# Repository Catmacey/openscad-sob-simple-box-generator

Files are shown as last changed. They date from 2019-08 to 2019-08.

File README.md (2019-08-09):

# OpenSCAD simple 3d printable project boxes

This is an OpenSCAD library for the creation of simple multipart project cases that can be 3d printed.  

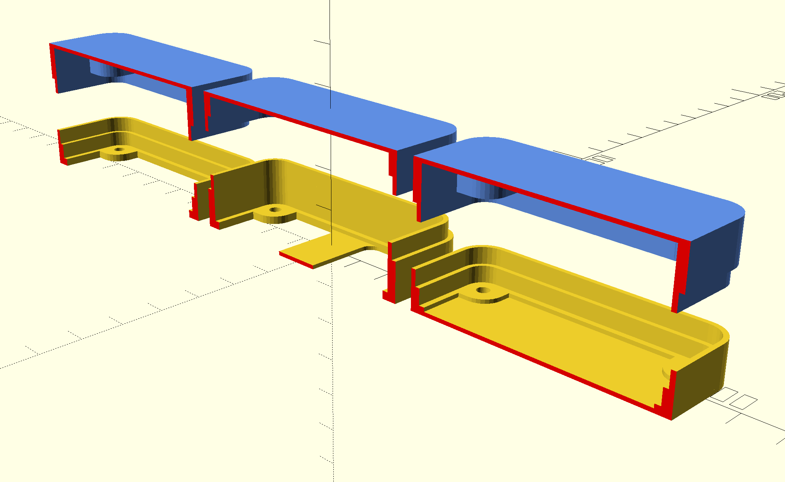
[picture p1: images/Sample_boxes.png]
Sample of three cases showing different options /tests/sob_tests.scad

>This image shows the case variants and is created from /tests/sob_tests.scad

The library is created in [OpenSCAD](http://www.openscad.org/) and is intended for 3d printing using a nothing-special FDM printer with a 0.4mm nozzle.

The box is split into three stacking parts, the top, middle and bottom (Not yet complete) and is designed to house electronics projects that use the Dangerous Prototypes [Sick Of Beige PCB standard](http://dangerousprototypes.com/docs/Sick_of_Beige_standard_PCB_sizes_v1.0).

The height, width and depth of the case are configurable to any dimensions (not just SOB standards) using "global" variables that you can override.  However the rounded corners and mounting hole locations and diameters are fixed based on the SOB standard.

The top and middle parts of the case interlock using an overlapping lip. The middle part of the case can have an open bottom, a single crosmember or be completely solid.  The entire case is held together by screws from underneath that screw into pads in the top.

### Example of DP5031 case

[DP5031 sample SCAD file](tests/DP5031.scad)

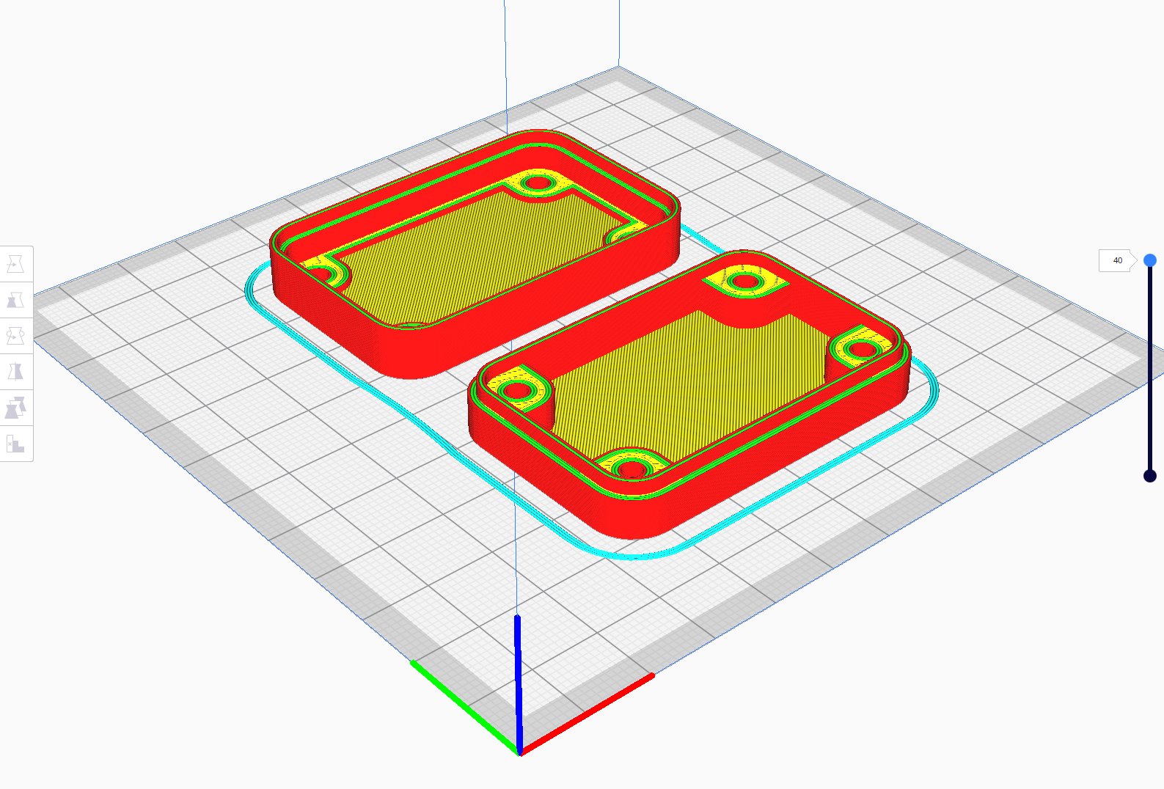
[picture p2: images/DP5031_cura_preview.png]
DP5031 Cura preview

>CURA preview

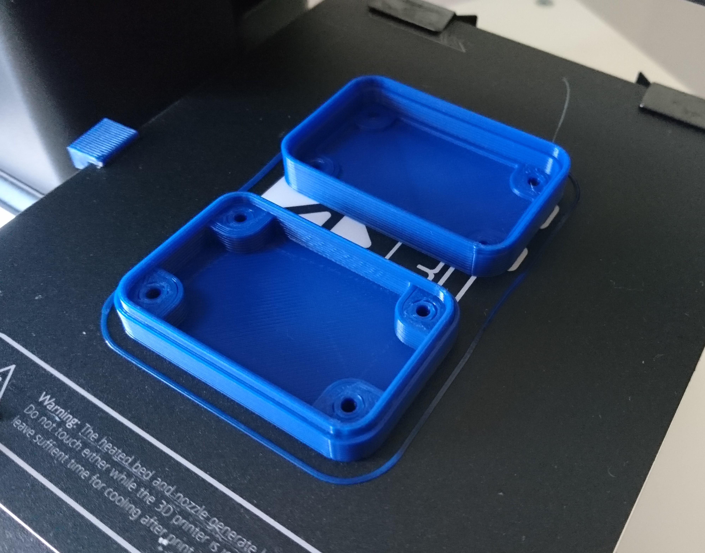
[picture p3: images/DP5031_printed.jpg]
DP5031 On the printer

>Printed in draft 0.4mm nozzle, 0.2mm layers

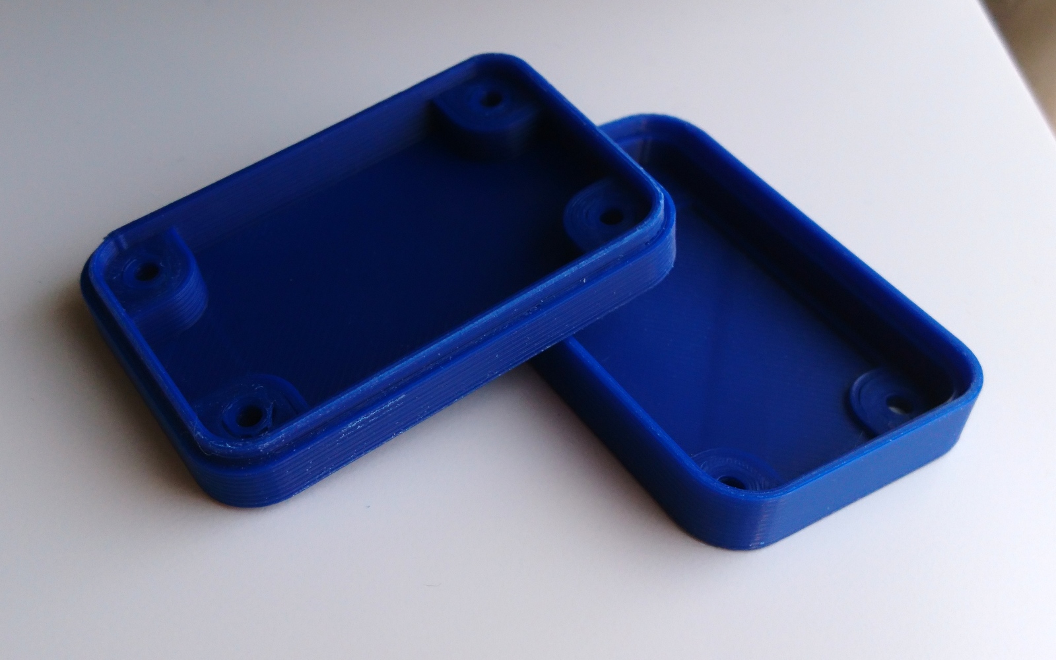
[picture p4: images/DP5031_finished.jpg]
DP5031 After a bit of tidying up

>After a bit of tidying up with a file and cutter to remove the first layer "splodge"

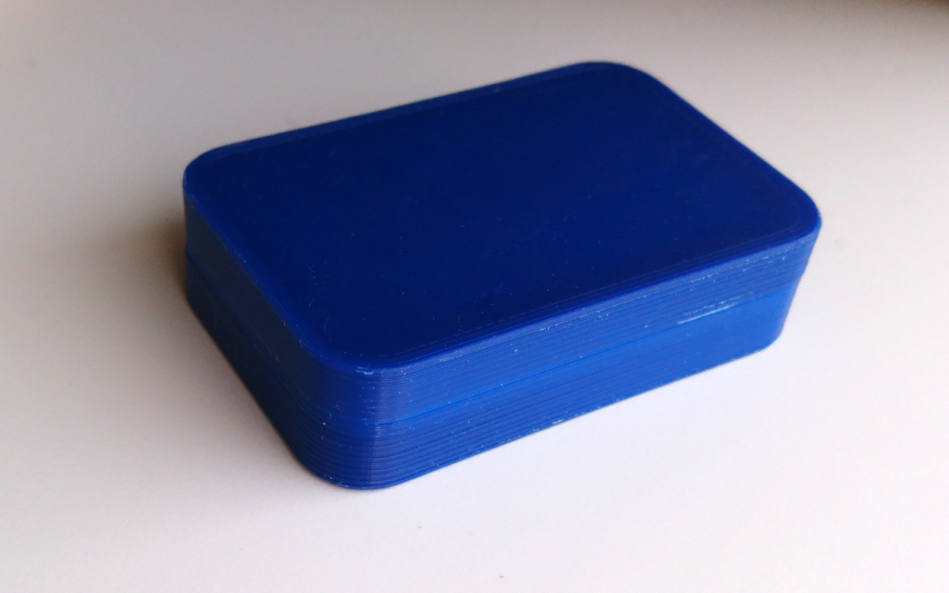
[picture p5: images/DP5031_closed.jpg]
DP5031 Closed case

>Completed case closed.  A small case like this one locks together very tighly.

Copyright (C) 2019 Matt Casey : catmacey.com
This program is free software: you can redistribute it and/or modify it under the terms of the GNU General Public License as published by the Free Software Foundation, either version 3 of the License, or (at your option) any later version.
	
This program is distributed in the hope that it will be useful, but WITHOUT ANY WARRANTY; without even the implied warranty of MERCHANTABILITY or FITNESS FOR A PARTICULAR PURPOSE.  See the GNU General Public License for more details.

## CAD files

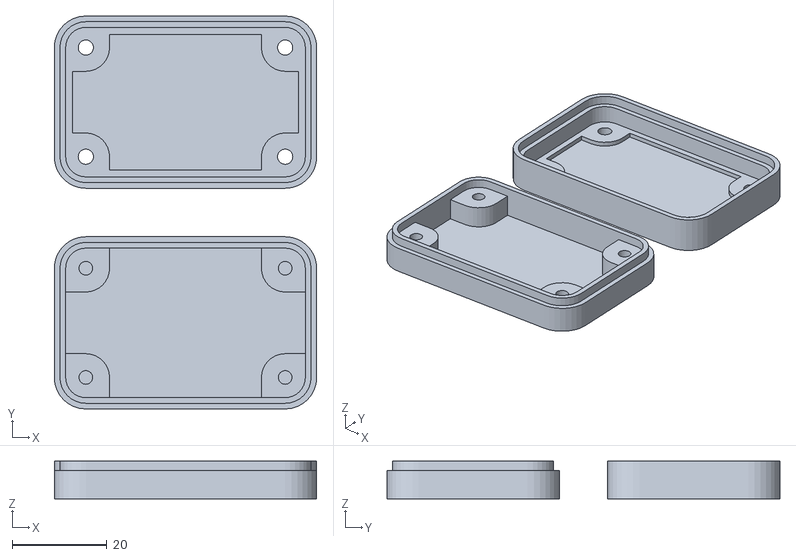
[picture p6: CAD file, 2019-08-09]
tests/DP5031.stl
55.3 x 82.8 x 8.00

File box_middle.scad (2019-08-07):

// Middle part of a SOB box
module sob_box_middle(
		overall_height = 10
	, lip_type = "outer"    // [inner|outer] which half of the lip is this?
	, xmember = 12          // [float] width of the crossmember. 0 for no crossmember
	, hollow = false        // [bool] solid or hollow base
	, cornerpad_thickness   // [float] height of the pads that support the pcb
	, withdrills = true     // [bool] do drill holes pierce through the bottom of the case
){
	union(){
		// Wall and lip
		translate([0,0,SOB_foot_thickness]){
			if(lip_type == "inner"){
				// Overall height does not include the lip
				translate([0,0,overall_height - SOB_foot_thickness]) sob_box_lip(type = lip_type);
				sob_wall(overall_height - SOB_foot_thickness);
			}
			if(lip_type == "outer"){
				translate([0,0,overall_height - SOB_foot_thickness - SOB_lip_thickness]) sob_box_lip(type = lip_type);
				sob_wall(overall_height - SOB_foot_thickness - SOB_lip_thickness);
			}
		}

		// Foot rim that the pcb sits on
		face(thickness = SOB_foot_thickness, hollow=true);

		// Thin xmember
		if(!hollow){
			face(thickness = SOB_foot_thickness/2, xmember = xmember, withdrills = withdrills);
		}

		// Pads that support the pcb
		// Default is that the corner pads in the middle part are flush
		// with the footrim but they can be thicker if you wish
		cp_thickness = 
			(cornerpad_thickness != undef)
			?cornerpad_thickness
			:SOB_foot_thickness
		;
		cornerpads(
			  drill = SOB_drill_radius
			, thickness = cp_thickness
		);
	}
}

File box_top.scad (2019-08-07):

// Top part of SOB box
module sob_box_top(
		overall_height = 10
	, lip_type = "inner"   // [inner|outer] which half of the lip is this?
	, cornerpad_thickness  // [float] height of the pads that support the pcb
){

	// This colour is of course completely optional :o)
	color("CornflowerBlue")
	union(){
		// Top face of the case
		translate([0,0,overall_height - SOB_face_thickness])
		face(thickness = SOB_face_thickness, hollow = false);

		// Wall and lip
		if(lip_type == "inner"){
			// Overall height does not include the lip
			translate([0,0,-SOB_lip_thickness]) sob_box_lip(type = lip_type);
			sob_wall(overall_height - SOB_face_thickness);
		}
		if(lip_type == "outer"){
			sob_box_lip(type = lip_type);
			translate([0,0,SOB_lip_thickness])
			sob_wall(overall_height - SOB_face_thickness - SOB_lip_thickness);
		}

		// Pads that you can screw into from below
		// Start from the face down to the lip
		// Default is that they extend to the same height as the inner face of
		// the wall (not including the lip) but they can be thicker or thinner if you wish
		// NOTE: The holes are smaller holes cos we want interference to screw into
		cp_thickness = 
			(cornerpad_thickness != undef)
			?cornerpad_thickness
			:overall_height - (lip_type == "inner"?0:SOB_lip_thickness) - SOB_face_thickness
		;
		translate([0,0,overall_height - SOB_face_thickness - cp_thickness]){
			cornerpads(
				  drill = (SOB_drill_radius * 0.9)
				, thickness = cp_thickness
			);
		}


	}
}

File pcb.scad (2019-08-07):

// DP SOB pcb format
module sob_pcb(
		width = SOB_pcb_width
	, height = SOB_pcb_height
	, thickness = SOB_pcb_thickness
	, pcb_corner_r = SOB_pcb_corner_radius // corner radius
	, drill_offset = SOB_drill_offset // mounting hole offset from edge of pcb
	, drill_r = SOB_drill_radius // mounting hole radius
	, colour = "ForestGreen"
){
	off_w = (width/2) - drill_offset;
	off_h = (height/2) - drill_offset;
	// The PCB
	color(colour, 1) render()
	linear_extrude(height = thickness, center = false, convexity = SOB_Convexity){
		difference(){
			minkowski(){
				square([width-(pcb_corner_r*2),height-(pcb_corner_r*2)], true);
				circle(r=pcb_corner_r);
			}
			for(coord = [
				[-off_w,-off_h],
				[-off_w,off_h],
				[off_w,off_h],
				[off_w,-off_h]
			]){
				translate([coord[0],coord[1],0]){
					circle(r=drill_r);
				}				
			}
		}
	}
}

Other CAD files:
sob.scad
tests/100x80x20.scad
tests/DP10080.scad
tests/DP5031.scad
tests/sob_tests.scad

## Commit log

2019-08-07 Initial release of box generator for Sick Of Beige (SOB) PCBs
    [100x80x20.scad, box_middle.scad, box_top.scad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]
2019-08-07 Added image of tests
    Added screen grab of sob_tests.scad
    Updated some of the comments to improve usability
    [sob.scad, sob_tests.scad]
2019-08-07 Fixed dependance on helpers.scad
    Removed include for helpers.scad. Moved the two needed modules into sob.scad
    [100x80x20.scad, sob.scad]
2019-08-07 Removed redundant variables
    Got rid of older redundant vars that have been replaced with _SOB_box_... vars
    Moved cornerpads into sob.scad
    [100x80x20.scad, box_middle.scad, box_top.scad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]
2019-08-09 Added DP5031 example
    Added images too
    [100x80x20.scad, DP5031.scad, DP5031.stl]
